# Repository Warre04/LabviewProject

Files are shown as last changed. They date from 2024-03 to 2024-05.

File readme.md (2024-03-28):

# RFID slot/deur

## Inputs	
  - RFID lezer
  - Keypad voor 'gasten'
  - Worden gelogd in CSV met huidige timestamp
  - Keypad codes kunnen aangemaakt worden en gekoppeld aan een naam, zal alleen werken in een bepaalde tijdsperiode (input csv?)

## Outputs
  - OLED schermpje
  - RGB led ring
  - Servo/magneet?

State machine gebruiken: `{waiting, authenticating, logging, openingDoor, closingDoor}`
		
Als er nog iets bij moet: weersensor & grafiek loggen (DHT-11?)

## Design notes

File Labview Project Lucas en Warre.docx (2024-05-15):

# Labview Project Lucas en Warre

Dit project stelt een automatisch slot voor dat te vinden kan zijn op bijvoorbeeld een hoteldeur. De deur kan geopend worden met een vooraf toegelaten RFID kaart of 4-cijferige code.

Bij het openen van de deur zal er in een csv-bestand worden bijgehouden met behulp van welke RFID kaart of code dit is gebeurd. Hierbij wordt ook de datum en het tijdstip opgeslagen.

# Opbouw hardware

Het project bestaat uit verschillende componenten:

- Arduino UNO R3
- 3x4 matrix keypad
- RFID-lezer module
- Adresseerbare LED-ring
- Led (als simulatie van het deurslot)

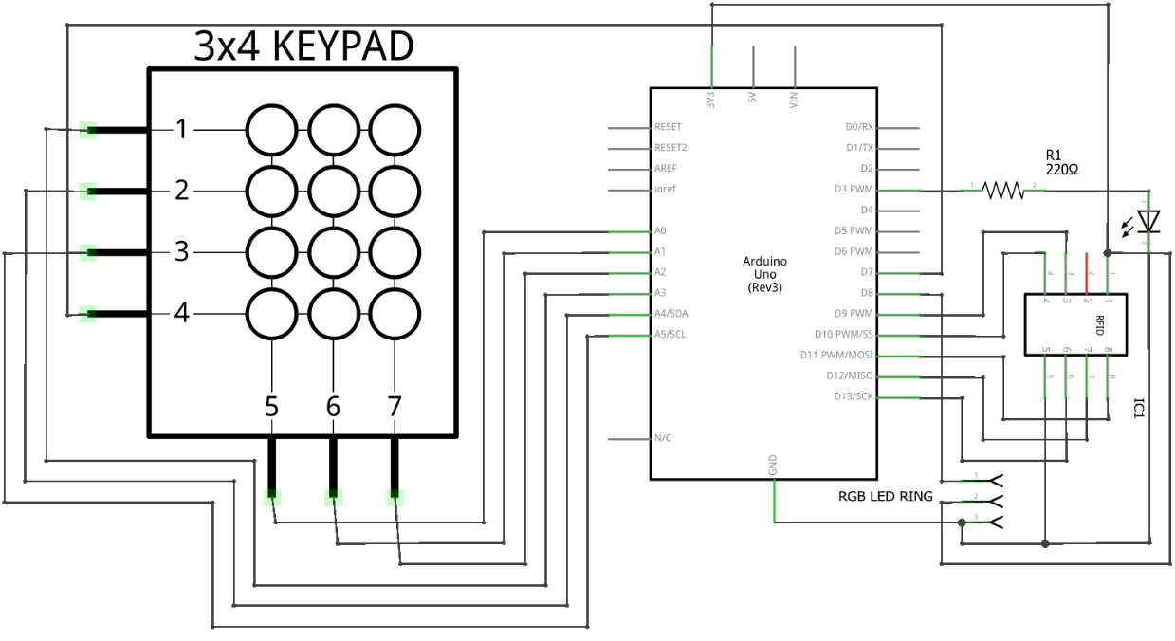
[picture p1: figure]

Figuur 1: elektronisch schema van het project. (Fritzing, sd)

Zoals weergegeven in figuur 1 is de keypad verbonden met de analoge ingangen en één digitale ingang. Deze keuze is gemaakt omdat er niet voldoende digitale pinnen over zijn en de RFID een vooraf opgelegde aansluiting heeft.

De RGB LED-ring is verbonden met één poort, digitale poort 8, en wordt gevoed door 3,3V.

De aansluiting van de RFID-module is vastgelegd door zijn bijhorende bibliotheek en zijn nodige protocollen. In dit project gebruiken we de Wadda variant van Velleman (Velleman, sd)

Als laatst is er nog een LED verbonden aan digitale poort 3 van de Arduino. Deze LED is echter alleen maar ter demonstratie. In werkelijkheid zou deze vervangen moeten worden door een magnetisch slot, een motor, of ander vergrendelingsmiddel.

# Werking Arduinocode

De Arduino code die gebruikt wordt is ontworpen om zo weinig mogelijk taken uit te voeren en enkel een communicatiebrug te zijn voor de hardware. Om het programma overzichtelijk te houden is het opgesplitst in meerdere bestanden en meerdere functies.

In de header file zijn alle bibliotheken geïnstantieerd en zijn alle declaraties opgesplitst in zijn categorie.

Het hoofdbestand is LabviewProject.ino, deze bevat enkel de setup en de loop functie. Als een module een setup nodig heeft van meer dan een regel krijgt deze zijn eigen functie in zijn eigen bestand. In de loop functie wordt er gecheckt of Labview via de seriële communicatiedata heeft doorgestuurd, als dat zo is zal er op basis van de waarde de juiste output aangestuurd worden. De RFID-module en de keypad sturen op hun buurt zelf data naar Labview met informatie over de input.

Voor meer informatie over de overige functies verwijzen we naar de Arduinocode.

# Werking LabViewcode

Het project is opgesteld in de vorm van een state machine. Bij het starten van het project zullen eerst alle geautoriseerde sleutels ingelezen worden. Dit gebeurt in de status update_array. Van zodra deze zijn ingelezen uit het CSV-bestand is het programma klaar voor gebruik en zit nu in de idle_checking status. Er start ook een wachtanimatie op de LED-ring.

Bij een input van een toegangsmogelijkheid zal er eerst gecheckt worden of dit RFID is of een cijfer van de keypad. Wanneer dit een RFID voorstelt, wordt eerst de seriële data aangepast naar een bruikbare string. Vervolgens wordt er gebruik gemaakt van een zelfgemaakte subVI die aan de hand van een meegegeven string en array checkt of deze string in de array aanwezig is.

Het checken van de aanwezigheid van de string gebeurt door de array te doorlopen (via index) en vervolgens elke waarde achter elke index te vergelijken met de string. Bij een overeenkomst stopt deze for-lus en wordt er een boolean teruggegeven. Op basis van deze boolean komt het project in de noAccess -of access_granted-status.

Een tweede input optie is door gebruik te maken van de keypad. Een cijfercode is vier getallen, maar met de keypad kan er maar één tegelijkertijd ingegeven worden. Bij het ontvangen van de keypad-data in Labview zal er eerst gecheckt worden of de vorige ingegeven data bij de code hoort (vooraf ingegeven getallen) of dat dit nog andere data was. De vorige data wordt bijgehouden door een shift register. Als dit bijhorende data is zal de nieuwe data bewerkt worden tot een bruikbare string en vervolgens samengevoegd worden met deze data. Vanaf dat de data string vier karakters bevat wordt er net zoals bij de RFID-kaart vervolgens gecheckt door de subVI of de code gekend is en op basis van de resulterende boolean verder gegaan naar een andere status.

Stemt de data niet overeen met iets uit de array zal er overgeschakeld worden naar de noAccess status. In deze status gebeurt er niets, de deur zal gesloten blijven. Er speelt enkel een animatie af op de LED-ring om de gebruiker te laten weten dat deur niet geopend wordt.

Stemt de data echter wel overeen met een waarde in de array, dan komt het systeem terecht in de access_granted-status. In deze status wordt er sequentieel een commando gestuurd om de deur te openen. Vervolgens wordt er een animatie gespeeld op de LED-ring en gewacht. Als laatst wordt de deur terug vergrendeld.

In parallel met deze commando’s wordt er opgeslagen wie er de deur heeft geopend en op welk tijdstip. Dit gebeurt door een zelfgemaakte subVI die als input een string en een bestandslocatie krijgt. De string wordt gecombineerd met de datum en tijd, gescheiden door komma’s, en vervolgens geschreven naar het log.csv-bestand.

Er kunnen ook nieuwe toegangscodes en RFID-kaarten toegevoegd worden. Dit gebeurt door na het lezen en omvormen van de data tot een string te checken of een knop in Labview is ingedrukt. Bij een cijfercode moet deze uit vier getallen bestaan. Als de knop ingedrukt is, zal er overgeschakeld worden naar de add_new_access_token status. Hierbij wordt er opnieuw een animatie afgespeeld op de LED-ring. In parallel wordt er gecheckt of de data die doorgegeven werd vanuit de vorige status geldig is. Als dat het geval is wordt deze als tekst toegevoegd onderaan in het bestand.

Na het opslaan van de data wordt het bestand terug ingelezen door de status update_array. Nu is deze data gekend in het programma en kan gebruikt worden om de deur te openen.

# Bibliografie

Fritzing. (sd). Fritzing. Opgehaald van Fritzing: https://fritzing.org/

Velleman. (sd). RFID schrijf en leesmodule. Opgehaald van Velleman: https://www.velleman.eu/products/view?id=459146

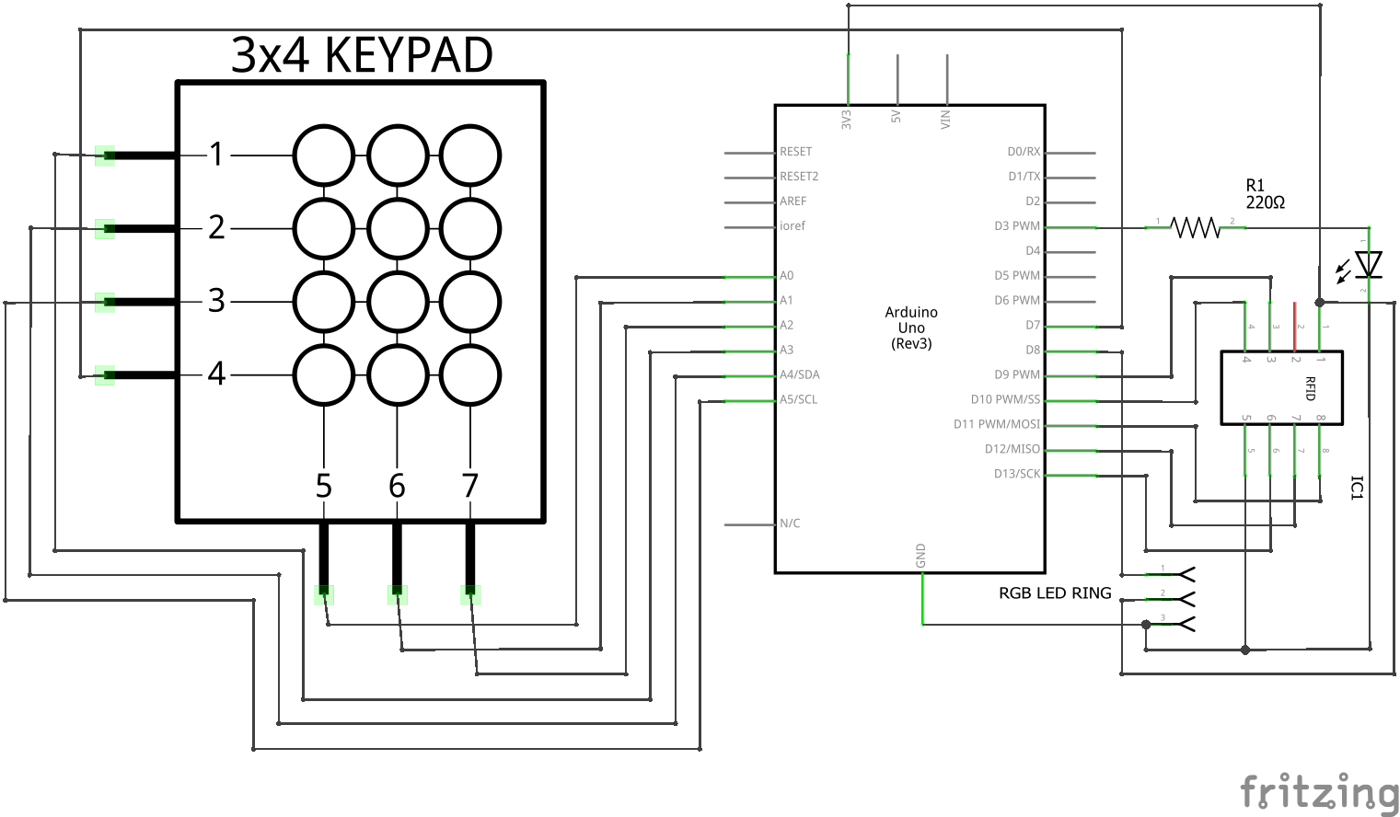
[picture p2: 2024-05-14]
schema.png

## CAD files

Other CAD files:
OldVersions/ViesCooleHouder.0004.ipt
ViesCooleHouder.ipt

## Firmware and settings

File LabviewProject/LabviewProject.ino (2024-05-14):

#include "PinDefinitions.h"

void setup() {
  pinMode(deurPin, OUTPUT);
  LedRingSetup();
  RFIDsetup();
  Serial.begin(19200);
  Serial.setTimeout(5);
}

void loop() {
  if (Serial.available() > 0) {
    String input = Serial.readString();
    if (input.equals("deurOpen")) {
      digitalWrite(deurPin, HIGH);
    } else if (input.equals("deurToe")) {
      digitalWrite(deurPin, LOW);
    } else if (input.equals("ledAllOff")) {
      LedAllOff();
    } else if (input.startsWith("led:")) {
      LedRing(input.substring(4, 6).toInt(), input.substring(6, 9).toInt());
    } else if (input.startsWith("noAccess")) {
      allStatusOff();
      NoAccessFlashes = 7;
    } else if (input.startsWith("idle")) {
      NoAccessFlashes = 0;
      ledRingAccess = false;
      ledRingAddAccess = false;
      ledRingIdle = true;
    } else if (input.startsWith("access")) {
      allStatusOff();
      ledRingAccess = true;
    } else if (input.startsWith("addAccess")) {
      allStatusOff();
      ledRingAddAccess = true;
    }
  }
  printKeypadIfPosible();
  runRFID();


  //doordat delay niet gebruikt kan worden en labvieuw te traag is voor de animaties gebruiken we millis en een boolean en staan de funcities voor de ledring animaties in de main
  addAccesKey();
  access();
  noAccess();
  idle();
}

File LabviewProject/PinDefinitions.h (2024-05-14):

#ifndef PIN_DEFINITIONS_H
#define PIN_DEFINITIONS_H
//included Librarys
#include <FastLED.h>
#include <Keypad.h>
#include <SPI.h>
#include <MFRC522.h>

//Door Lock System
#define deurPin 3 //door pin number

//Circular LED array
#define NUM_LEDS 24 //amount of LEDs in the circular LED array
#define DATA_PIN 8 //Datapin from the circular LED array
CRGB leds[NUM_LEDS]; //the array of LEDs

//KeyPad
#define ROWS 4  //Row amount
#define COLS 3  //Collums amount
char keys[ROWS][COLS] = { //KeyPad layout
  { '1', '2', '3'},
  { '4', '5', '6' },
  { '7', '8', '9' },
  { '*', '0', '#' }
};
byte rowPins[ROWS] = { A3, A4, A5, 7 };  //Pins used for the rows of the Keypad    
byte colPins[COLS] = { A0, A1, A2 };  // pins used for the cols of the keypad
Keypad keypad = Keypad(makeKeymap(keys), rowPins, colPins, ROWS, COLS); // create Keypad


#define SS_PIN 10  // Definieer de Slave Select Pin
#define RST_PIN 9  // Definieer de Reset Pin

MFRC522 mfrc522(SS_PIN, RST_PIN); 

//Global Var for LEDRING modes
int NoAccessFlashes=0;
bool ledRingIdle=false;
bool ledRingAccess=false;
bool ledRingAddAccess=false;

#endif

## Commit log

2024-04-11 added basic arduino program for LED ring
2024-04-15 added basic arduino program for keypad
2024-04-18 rfid toegevoegd aan arduino code
2024-04-18 headerfile toegevoegd en begonnen aan inventor file
    [ViesCooleHouder.ipt]
2024-04-25 rfid is werkende
    [authorisedRFID.csv]
2024-04-25 vies coole led ring nest
    [ViesCooleHouder.ipt, authorisedRFID.csv]
2024-04-25 led ring sub vi af
    [authorisedRFID.csv]
2024-05-13 access logging toegevoegd, geen idee of het werkt
2024-05-14 added log.csv
    [authorisedRFID.csv, log.csv]
2024-05-14 finished labvieuw
    [authorisedRFID.csv, log.csv]
2024-05-14 added commentaar toe arduino
    [ViesCooleHouder.0003.ipt, ViesCooleHouder.ipt, authorisedRFID.csv]
2024-05-14 extra commentaar en verslag v1 geschreven
    [Untitled Sketch.fzz, authorisedKeys.csv]
2024-05-15 updated houder
    [ViesCooleHouder.0003.ipt, ViesCooleHouder.0004.ipt, ViesCooleHouder.ipt]
2024-05-15 kabels wat geordend haha
    [authorisedKeys.csv, log.csv]
